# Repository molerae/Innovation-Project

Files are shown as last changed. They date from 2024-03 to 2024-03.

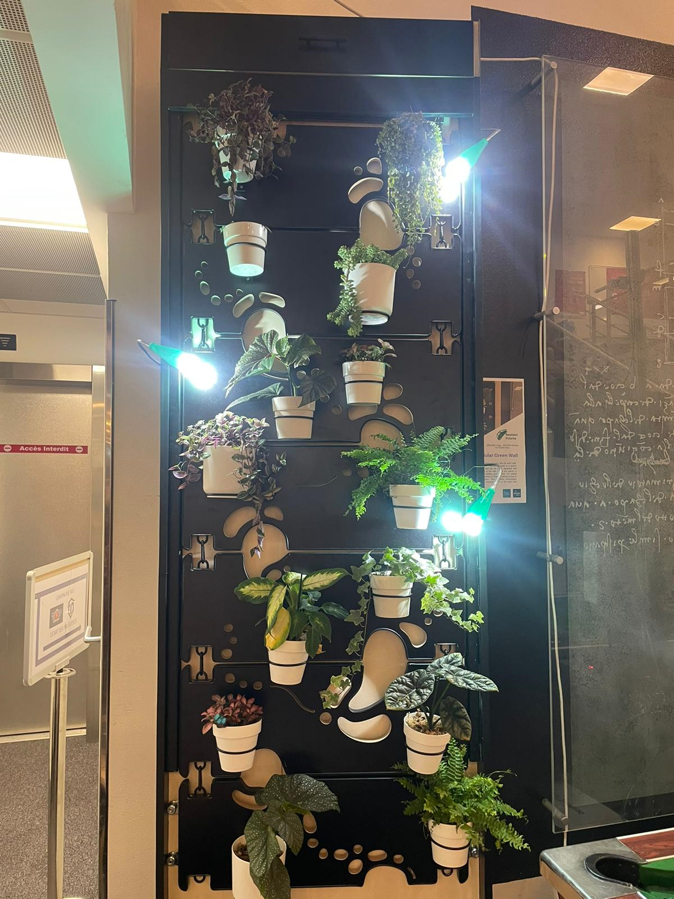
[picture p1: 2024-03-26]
Mur végétal final allumé.png

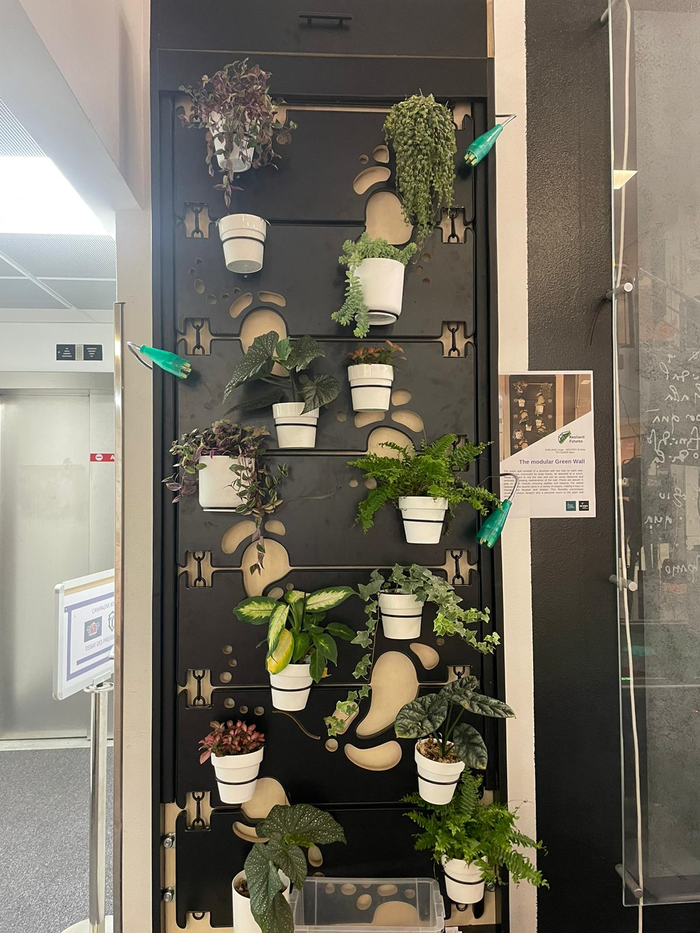
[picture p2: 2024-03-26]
Mur végétal final éteint.png

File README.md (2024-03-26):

# Innovation-Project

## Philosophy 

My desire to get into the concrete and energize my studies led me to DVIC. Being part of the DVIC allows me both to satisfy my curiosity and to directly apply the knowledge I've been lucky enough to acquire. Project-based learning encourages creativity and autonomy. 

### The modular green wall 

A review of existing green wall solutions has revealed the diverse benefits they offer. However, indoor green walls pose unique challenges, requiring special attention to maintenance, lighting and water. The aim of this project is to meet these challenges with a carefully designed structure of interconnected rectangular modules and a modular design allowing flexibility in location, rotation and custom design.

### Vision : Reconnect people with nature

We believe in a profound reconnection with nature, which we consider essential to our well-being. That's why we aim to establish a plant-based system designed for urban environments, accessible to all. With 45% of the French population living in apartments without gardens, we are focused on creating a versatile indoor plant system(https://dvic.devinci.fr/projects/modular-green-wall#fn4). Aware of the difficulties involved in maintaining plants, particularly in terms of time, we want to minimize the need for maintenance. Our vision is to reconnect people with nature and demonstrate its anti-stress and productive benefits through a modular, low-maintenance houseplant system. The system is designed to be almost 100% self-sufficient, considerably reducing the time needed to maintain the plants. Its modularity allows users to express their creativity by modifying the system effortlessly. By introducing plants indoors, the idea is to create a daily visual link with nature, thereby improving the quality of life for city dwellers.

### The structure

The green wall is made up of a structure with two rails on each side and interconnected rectangular modules. These modules fit into the rails, providing support for the green wall. Plants are placed in two pots on each module, ensuring perfect stability and balance due to the thoughtful placement of the pots relative to the structure's center.

For flexibility, the modules come in various shapes, allowing easy changes in placement and rotation (in x and y directions). This flexibility promotes creativity, unique designs, and a personal touch to the green wall structure. Maintenance is simplified with a self-braking winch. Modules can be easily detached and removed from the rail. The same principle is applied when putting modules back in place, allowing for easy modification of the green wall's design and maintenance.

### The lighting system

Finally, lamps system are added to ensure the survival of the plants. The goal is to create modulable lamps that are perfectly adapted to the plant on the wall. I didDIY lamps that we can place wherever we want on the wall, with a arm that can twist and with the right intensity of the leds thanks to calculations about the lumens needed to illuminate each type of plant.

### List of Material

A number of essential materials are required to complete the project:

- To ensure a robust electrical connection -> minimum 10-meter-long electrical wire with a 1.5 mm² cross-section 

- For efficient energy management/power supply -> plugs and a 4-socket power strip 

- For lighting -> G4 bulbs and 12V G4 sockets

- To automate the lighting cycle -> square mechanical programmer

- For easy manual control -> black switch 6A at 250V

- To ensure a neat layout -> cable ties in sufficient quantity (approx. 60)

- To protect connections and ensure proper insulation -> heat-shrink tubing

- To power LEDs safely -> transformer compatible

### How to do the maintenance of the wall ?

[Regarder la vidéo sur YouTube](https://www.youtube.com/watch?v=8U8inEAfjAI)

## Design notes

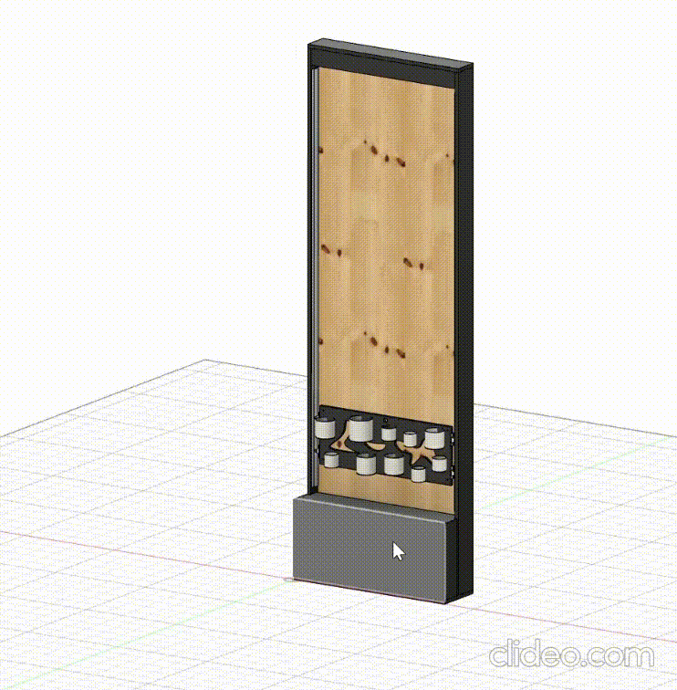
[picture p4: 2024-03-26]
Gif Modélisation.gif

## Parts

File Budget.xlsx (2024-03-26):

Produit | Site | Prix à l’unité | Nb | Prix total | Commandé | Reçu | Date
Equerres 30x30x38mm (https://www.amazon.fr/%C3%A9querre-Fixation-30x30x38-Equerre-Montage/dp/B0CC5VYQRZ) | Amazon | 15.99 € | 1 | 15.99 € | Oui | Oui | 2024-10-05
Colle bois (https://www.amazon.fr/Uhu-Colle-Bois-Prise-Rapide/dp/B071RH683S?sp_csd=d2lkZ2V0TmFtZT1zcF9hdGY) | Amazon | 7.90 € | 1 | 7.90 € | Oui | Oui | 2024-10-05
Colle tout (https://www.amazon.fr/Pattex-Colle-fixation-One-Universal/dp/B015T14FBE?rnid=15431318031) | Amazon | 9.00 € | 1 | 9.00 € | Oui | Oui | 2024-10-05
Tourillons 6x50 (https://www.amazon.fr/FTVOGUE-Tourillons-Chevilles-goupilles-Menuiserie/dp/B07W992J3H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) | Amazon | 7.42 € | 1 | 7.42 € | Oui | Oui | 2024-10-05
Tourillons 6x30 (https://www.amazon.fr/Wolfcraft-2906000-tourillons-%C3%B86x30-Beige/dp/B0001P19DG) | Amazon | 2.50 € | 3 | 7.50 € | Oui | Oui | 2024-10-05
Contreplaqué noir n°1 800x300x18 (https://www.amazon.fr/gp/product/B07Z978QCJ/ref=ox_sc_act_title_1?smid=AE8A0P7LENY3B&th=1) | Amazon | 38.95 € | 7 | 273.65 € | Oui | Oui | 2024-11-02
Contreplaqué noir n°2 1000x900x18 (https://www.amazon.fr/gp/product/B07Z97LYRM/ref=ox_sc_act_title_1?smid=AE8A0P7LENY3B&th=1) | Amazon | 132.57 € | 2 | 265.14 € | Oui | Oui | 2024-11-02
Contreplaqué noir n°3 1300x600x18 (https://www.amazon.fr/gp/product/B07Z97N2YH/ref=ox_sc_act_title_1?smid=AE8A0P7LENY3B&th=1) | Amazon | 120.45 € | 1 | 120.45 € | Oui | Oui | 2024-11-02
Contreplaqué épicéa 2500x1220x19 (https://www.leroymerlin.fr/produits/menuiserie/panneau-planche-et-materiaux-bois/panneau-bois-agglomere-mdf/panneau-bois-recoupable/panneau-contreplaque-3-pli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) | Leroy Merlin | 149.90 € | 1 | 149.90 € | Oui | Oui | 2024-11-02
Lasure bois 750ml Incolore (https://www.amazon.fr/LASURE-prot%C3%A8ge-d%C3%A9core-embellit-INCOLORE/dp/B08Q7XTC4Y?rnid=83034110031&s=hi) | Amazon | 14.45 € | 1 | 14.45 € | Oui | Oui | 2024-11-02
Rail (https://www.amazon.fr/tendaggimania-Coulissant-coulissantes-Personnalisable-Accessoires/dp/B07MTK5NZV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) | Amazon | 46.10 € | 2 | 92.20 € | Oui | Oui | 2024-11-02
Spray noir pour rail (https://www.amazon.fr/dp/B004AHOTX8/?coliid=I166YBOVO45RON&colid=KYV9ZLFXLSZS) | Amazon | 9.99 € | 1 | 9.99 € | Oui | Oui | 2024-11-02
Chevilles pour fixation
Total |  |  |  | 973.59 €
Maintenance
Produit | Site | Prix à l’unité | Nb | Prix total | Commandé | Reçu | Date
Poulie de levage (x4) (https://www.amazon.fr/Poulie-Simple-pour-Levage-Mouflage/dp/B09VK5C1YL?sp_csd=d2lkZ2V0TmFtZT1zcF9hdGY) | Amazon | 14.99 € | 1 | 14.99 € | Oui | Oui | 2024-10-05
Treuil Manuel 350kg (https://www.amazon.fr/GOYADA-Treuil-Manuel-360kg-800lbs/dp/B0B4ZNRY15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) | Amazon | 37.99 € | 1 | 37.99 € | Oui | Oui | 2024-10-05
Manchons câble métallique | Perso | 10.58 € | 1 | 10.58 € | Oui | Oui | 2024-10-25
Bague d’arrêt (https://www.amazon.fr/Ensemble-forets-Positionneur-danneau-profondeur/dp/B07JZ7SH36?rnid=83034110031&s=hi) | Amazon | 8.69 € | 1 | 8.69 € | Oui | Oui | 2024-11-02
Total |  |  |  | 72.25 €
Modules
Produit | Site | Prix à l’unité | Nb | Prix total | Commandé | Reçu | Date
Grillage noir 100cm x 5m (https://www.manomano.fr/p/fil-de-voliere-4-coins-avec-maille-de-12x12mm-100cmx5m-en-noir-30119337) | Mano Mano | 15.99 € | 1 | 15.99 € | Oui | Oui | 2024-10-10
Mousquetons x10 (https://www.amazon.fr/smatime-Mousquetons-Aluminium-Mousqueton-Carabiner/dp/B09FP6L8X5?rnid=15431318031) | Amazon | 7.99 € | 2 | 15.98 € | Oui | Oui | 2024-10-05
Rouleau caoutchouc (https://www.amazon.fr/caoutchouc-%C3%A9paisseur-revetement-protection-antid%C3%A9rapant/dp/B0BPDLQBX2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) | Amazon | 14.60 € | 1 | 14.60 € | Oui | Oui | 2024-10-05
Roulettes 18mm (https://www.amazon.fr/mini-roulettes-caoutchouc-plastique-fix%C3%A9es-pivotant/dp/B07B2HGVWJ?rnid=15431318031) | Amazon | 16.99 € | 1 | 16.99 € | Oui | Oui | 2024-10-10
Chaine fixation 99cm (https://www.amazon.fr/Cha%C3%AEne-mousquetons-fixation-variable-chaise/dp/B07QFN5XM4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) | Amazon | 14.95 € | 2 | 29.90 € | Oui | Mouais | 2024-10-10
Fil Jardinage 100m (https://www.amazon.fr/KINGLAKE-Cravate-v%C3%A9g%C3%A9taux-torsad%C3%A9s-Plastique/dp/B07S215ZJ7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) | Amazon | 11.99 € | 1 | 11.99 € | Oui | Oui | 2024-10-10
Ficelle 4mm x 30m (https://amazon.fr/Ficelle-d%C3%A9paisseur-r%C3%A9sistante-d%C3%A9coration-emballage/dp/B0B93S3DJM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) | Amazon | 8.99 € | 1 | 8.99 € | Oui | Oui | 2024-10-10
Serres joints 150x2.5mm (https://www.amazon.fr/ERKO-dattaches-professionnelles-r%C3%A9sistante-temp%C3%A9rature/dp/B08SNN57KP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) | Amazon | 6.60 € | 1 | 6.60 € | Oui | Oui | 2024-10-10
Finitions 5m x 15mm (https://www.amazon.fr/Flexible-Autocollante-Travail-Garniture-prot%C3%A9ger/dp/B0BKRR62SD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) | Amazon | 18.78 € | 4 | 75.12 € | Oui | Oui | 2024-11-02
Crochets pour pots | Perso | 5.59 € | 1 | 5.59 € | Oui | Oui | 2024-10-10
Pots Ronds Blancs D13 d9.8 H12.4 x3 (https://www.amazon.fr/dp/B0843CSGS8/ref=emc_b_5_t?th=1) | Amazon | 14.95 € | 1 | 14.95 € | Oui | Oui | 2024-12-04
Pots Ronds Gris D13 d9.8 H12.4 x3 (https://www.amazon.fr/dp/B0843CRFGW/ref=emc_b_5_t?th=1) | Amazon | 14.95 € | 1 | 14.95 € | Non | Non | 2024-12-04
Pots Cônes Blancs D12 H10.7 x6 (https://www.amazon.fr/idea-station-jardini%C3%A8res-int%C3%A9rieur-ext%C3%A9rieur-incassables/dp/B07JM6CP71) | Amazon | 16.95 € | 1 | 16.95 € | Oui | Oui | 2024-12-04
Pots Cônes Gris D12 H10.7 x6 (https://www.amazon.fr/idea-station-jardini%C3%A8res-int%C3%A9rieur-ext%C3%A9rieur-incassables/dp/B08N6NT5JG) | Amazon | 17.95 € | 0 |  | Non | Non | 2024-12-04
Total |  |  |  | 248.60 €
Plantes
Produit | Site | Prix à l’unité | Nb | Prix total | Commandé | Reçu | Date
Terreau (https://www.truffaut.com/terreau-terre-vie-plantes-interieur-15-l-749120.html) | Truffault | 10.99 € | 1 | 10.99 € | oui | oui
Perlite (https://www.truffaut.com/perlite-sac-5-litres-753207.html) | Truffault | 10.49 € | 2 | 20.98 € | oui | oui
Sphaigne (https://www.truffaut.com/sphaigne-5l-501761.html) | Truffault | 17.49 € | 2 | 34.98 € | oui | oui
Plante n°1 (https://www.truffaut.com/monstera-deliciosa-feuille-de-fenetre-pot-de-12cm-ca-30-35cm-de-haut.html) | Truffault | 11.77 € | 2 | 22.34 € | oui | oui
Plante n°2 (https://www.truffaut.com/feuille-begonia-silver-jewel-begonia-royal-begonia-feuille-bijoux-pot-12cm.html) | Truffault | 21.31 € | 1 | 21.31 € | oui | oui
Plante n°3 (https://www.truffaut.com/philodendron-scandens-brasil-arbre-grimpant-ami-bicolore-pot-12cm.html) | Truffault | 7.28 € | 2 | 14.56 € | oui | oui
Plante n°4 (https://www.truffaut.com/plante-d-interieur-fougere-de-boston-30cm.html) | Truffault | 16.00 € | 1 | 16.00 € | oui | oui
Plante n°5 (https://www.truffaut.com/tradescantia-zebrina-suspension-diametre-18cm-695009.html) | Truffault | 20.49 € | 1 | 20.49 € | oui | oui
Total |  |  |  | 161.65 €
Eclairage
Produit | Site | Prix à l’unité | Nb | Prix total | Commandé | Reçu | Date
Fil électrique 10m x 1.5mm² (https://www.amazon.fr/C%C3%A2ble-dalimentation-%C3%A9lectrique-HO5VV-F-Blanc/dp/B01GCWXL9Q?rnid=15431318031) | Amazon | 15.90€ | 1 | 15.90€ | Oui | Oui | 2024-11-02
Prise électrique mâle (https://www.amazon.fr/Debflex-713520-droite-portefeuille-coiffe/dp/B00GWP9S78?rnid=15431318031) | Amazon | 2.86 € | 1 | 2.86 € | Oui | Oui | 2024-11-02
Multiprise 4 prises (https://www.amazon.fr/Bloc-Prises-16A-Interrupteur-Blanc/dp/B09F5WZ5FF) | Amazon | 5.50€ | 1 | 5.50 € | DVIC | DVIC | 2024-11-02
Programmateur mécanique carré (https://www.amazon.fr/Lifedom-Programmateur-Journalier-M%C3%A9canique-Inter/dp/B00BW4VUAW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) | Amazon | 5.99 € | 1 | 5.99 € | DVIC | DVIC | 2024-11-02
Interrupteur noir 6A 250V (https://www.amazon.fr/FUJIE-Interrupteur-Bi-polaire-Electrique-Souple/dp/B07L4G24G2?rnid=15431318031) | Amazon | 3.50 € | 1 | 3.50 € | Oui | Oui | 2024-11-02
Attaches câbles 60 (https://www.amazon.fr/Armiz-Lot-attaches-c%C3%A2ble-r%C3%A9utilisables/dp/B092DSRD5L?rnid=15431318031) | Amazon | 6.99€ | 1 | 6.99€ | Oui | Oui | 2024-11-02
Gaines Thermo rétractables (https://www.amazon.fr/Arnocanali-gaines-thermor%C3%A9tractables-color%C3%A9es-pi%C3%A8ces/dp/B081HPS8C9) | Amazon | 2.90 € | 1 | 2.90 € | Oui | Oui | 2024-11-02
Ampoules G4 (https://www.amazon.fr/correspond-halog%C3%A8nes-dimmable-d%C3%A9clairage-lumi%C3%A8re/dp/B07VJ2R5RK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) | Amazon | 16.98€ | 1 | 16.98 € | Oui | Oui | 2024-11-02
Douille G4 12V (https://www.amazon.fr/Douille-support-c%C3%A9ramique-halog%C3%A8nes-plafonniers/dp/B083GG9T2D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) | Amazon | 9.99 € | 1 | 9.99 € | Oui | Oui | 2024-11-02
Transformateur (https://www.amazon.fr/gp/product/B0C8CHZKJ1/ref=ox_sc_act_image_1?smid=A1YRIP30OPSYDX&th=1) | Amazon | 21.99 € | 1 | 21.99 € | Oui | Oui | 2024-11-02
douille + cordon flexible (https://www.amazon.fr/DiCUNO-r%C3%A9glable-adaptateur-dextension-convertisseur/dp/B07P6K4LNG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) | Amazon | 13.99 € | 1 | 13.99 € | Oui | Oui | 2024-11-02
Peinture noir spray (https://www.amazon.fr/Spectrum-Brillant-Peinture-A%C3%A9rosol-4x400ml/dp/B08L9DZLHP?rnid=83034110031&s=hi)
Boites de conserve x15
3D-printing support abat-jour | DVIC | / | 15 | / | / | /
Support Fixation Plateforme | DVIC | / | 15 | / | / | /
Total |  |  |  | 72.21 €
SOMME TOTALE |  |  | 1528.30 €

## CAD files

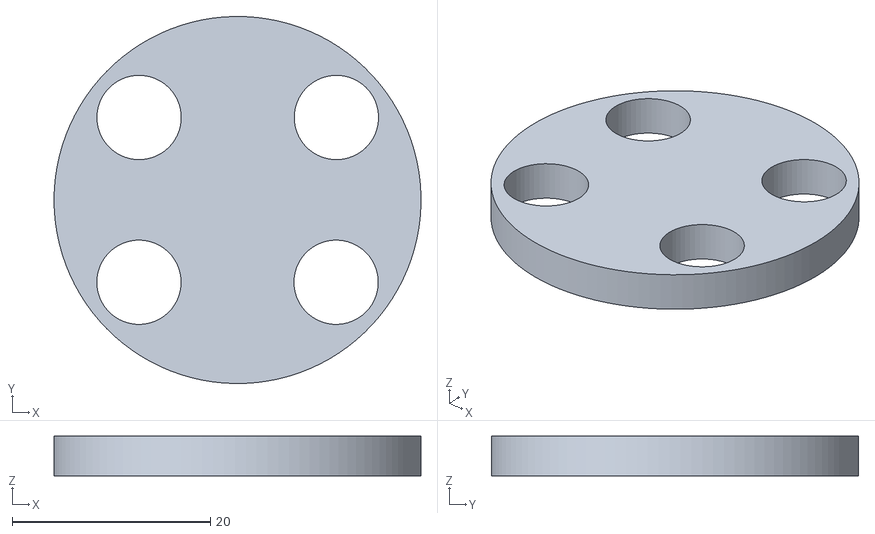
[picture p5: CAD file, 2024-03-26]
FixateurLampe v4.stl
37.0 x 37.0 x 4.00

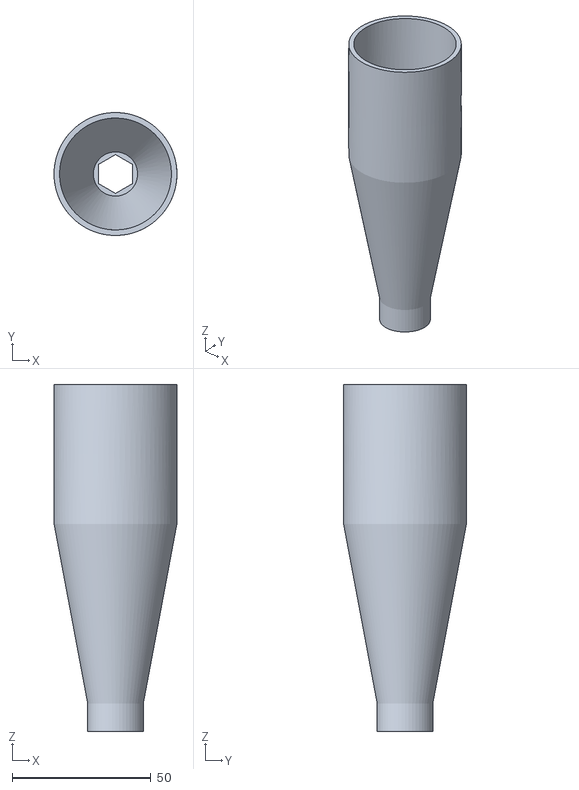
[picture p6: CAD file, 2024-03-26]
ConeLampe v2.stl
44.3 x 44.3 x 125.0
